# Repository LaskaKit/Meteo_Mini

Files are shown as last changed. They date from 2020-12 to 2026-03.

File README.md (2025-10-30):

# LaskaKit Meteo Mini with ESP32-C3 — More Powerful and Energy Efficient

A weather station is one of the most popular projects among makers.  
Blinking an LED is fun at first, but it gets boring quickly.  
When you build your own weather station, it will serve you for a long time — the longer it runs, the better, as you’ll collect long-term statistics.  
And with your own station, you might even detect a volcanic eruption on the other side of the world (thanks to a pressure sensor recording the shockwave).

We know not everyone can or wants to design their own hardware, so we’re introducing our development board designed specifically (but not only) for weather stations — [**LaskaKit Meteo Mini**](https://www.laskakit.cz/laskakit-meteo-mini).

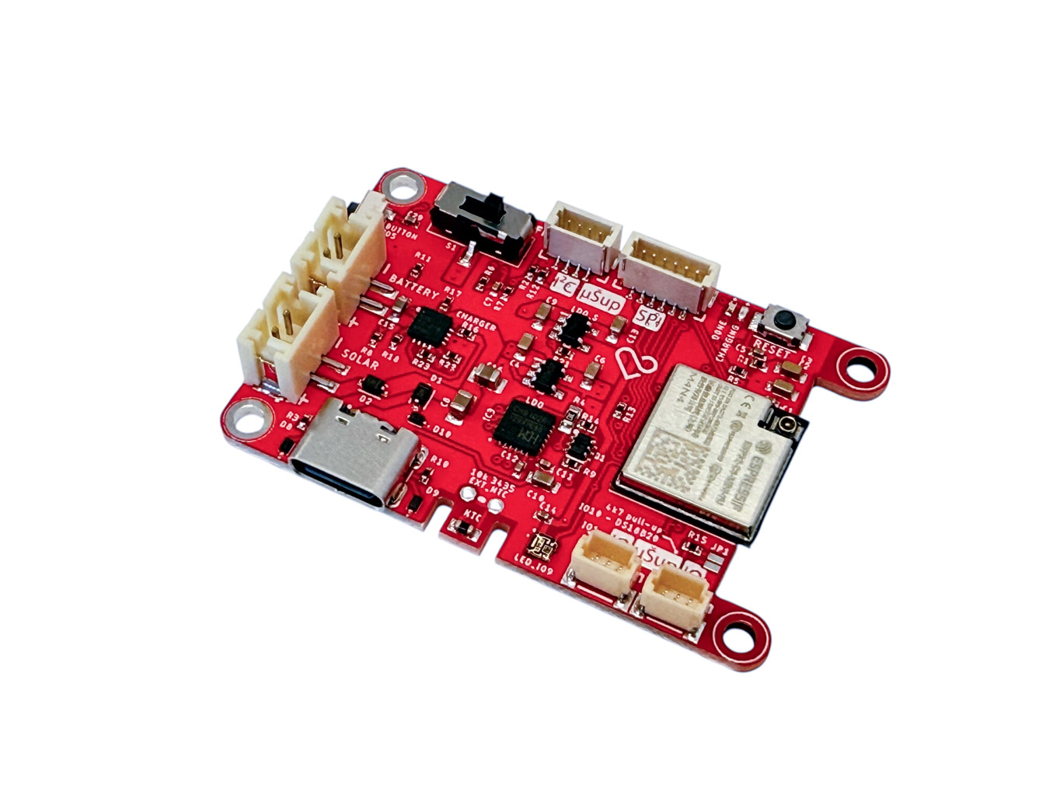
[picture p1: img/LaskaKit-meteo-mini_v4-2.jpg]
LaskaKit Meteo Mini v4.1 and newer


This development board based on **ESP32-C3** (a major upgrade from the older, less efficient ESP12S/ESP8266 version) makes building your weather station easier.  
It includes everything you need to get started — and can be easily expanded with additional sensor modules.

---

## 🧩 Specifications

| Parameter | Value |
|---|---|
| **Board version** | v4.1 |
| **Microcontroller** | ESP32-C3-MINI (Wi-Fi, BLE, RISC-V core) |
| **USB input voltage** | 3.4–5.5 V |
| **Solar input voltage** | 5–10 V *(recommended 6 V solar panel)* |
| **Deep-sleep current consumption** | 23 μA |
| **Antenna connector (IPEX version)** | [IPEX3](https://www.laskakit.cz/vyhledavani/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) |
| **Power supply** | USB-C or single-cell Li-Ion battery |
| **Charging IC** | BQ24074RGTR with charging indicators *(LED CHG/POWER GOOD)*.NTC allows battery charging only within the safe temperature range of 0 °C to 50 °C. |
| **USB interface** | CH9102F |
| **Voltage regulators** | RT9080 (ESP), RT9080 (peripherals, IO4 → HIGH to enable) |
| **Dimensions** | 48.4 × 32.9 × 9 mm |
| **Weight** | 8 g |

---

## ⚙️ Board Pinout

On the front of the board, you’ll find the Wi-Fi module with ESP32-C3.  
It delivers higher performance than the older ESP8266 version and is much more energy-efficient — consuming only **23 μA** in deep-sleep mode.

The module supports **IEEE 802.11 b/g/n** Wi-Fi standards.  
The **CH_CURRENT** solder bridge allows you to set the maximum charging current for the battery: **1.0 A or 1.34 A**, depending on resistor configuration (see schematic).

The board can be powered off using the onboard power switch.  
On the right side, there’s a **USB-C connector** for charging and power input.  
At the bottom, you’ll find connectors for a **Li-Ion battery (Battery)** and a **solar panel (Solar)**.

On the right side, there’s also a **1-Wire interface** for the **DS18B20 temperature sensor** (GPIO10).  
On the left side, you’ll find a set of **µSup connectors** – our custom connector standard compatible with **SparkFun Qwiic** and **Adafruit STEMMA**.  
In addition to the standard **I2C µSup connector**, there are also **µSup SPI** and **µSup IO** connectors.

Power for the µSup connectors is controlled via **GPIO4 (HIGH = enabled)**, allowing for even lower power consumption.  
A 3.3 V voltage regulator is integrated directly on the board.  
Battery voltage is measured using a voltage divider (1 MΩ and 1.3 MΩ) connected to **IO0 (ADC input)**.

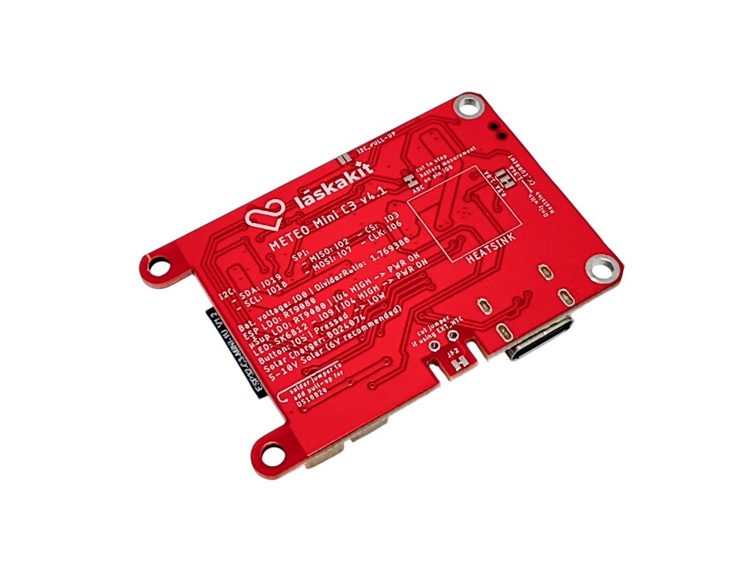
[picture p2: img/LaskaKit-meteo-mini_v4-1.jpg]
LaskaKit Meteo Mini with ESP32-C3 pinout


---

## 🔌 Sensor Connections

| Interface | Connector | Signals |
|---|---|---|
| **µSup I2C** | JST-SH 4-pin | SDA: IO19, SCL: IO18 |
| **µSup SPI** | JST-SH 6-pin | CS: IO3, MOSI: IO7, SCK: IO6, MISO: IO2 |
| **µSup IO** | 2× JST-SH 3-pin | IO1, IO10 *(supports DS18B20)* |

---

## ⚡ Battery and Solar Panel Connection

Power from USB-C and the solar panel is combined through protection diodes into the input of the **BQ24074** charging IC.  
Connecting both power sources simultaneously is safe.  
The **recommended solar panel** is 6 V, but **10 V panels can also be safely used**.  
Charging current is **configurable using the CH_CURRENT solder jumpers**: **0.5 A (default)**, **1.0 A**, or **1.34 A** *(when all three jumpers are bridged)*.  
Charging status is indicated by LEDs — **CHG** (charging) and **POWER GOOD** (fully charged).

---

## 🔋 Battery Voltage Measurement

The battery voltage (**VCC**) is connected through a resistor divider to the **IO0 (ADC)** input of the ESP32-C3 microcontroller.

---

## 💡 LEDs and Sensors

- **Addressable RGB LED:** SK6812-EC20 on IO9  
- **Button:** IO5 → pressed = LOW  
- **Temperature sensor:** NTC 10 kΩ (3435) – for battery temperature monitoring  

---

## 🧠 Programming

Install [ESP32-C3 support](https://github.com/espressif/arduino-esp32) in Arduino IDE.  
For versions **3.5 and newer** (including **v4.1**), **no external programmer** is required — the CH9102F interface is already integrated on the board.  
Older versions can use the [CH340C programmer](https://www.laskakit.cz/laskakit-ch340-programmer-usb-c--microusb--uart/).

---

## 💾 Example Code

Example code and libraries are available here:  
👉 [https://github.com/LaskaKit/Meteo_Mini/tree/main/SW/](https://github.com/LaskaKit/Meteo_Mini/tree/main/SW/)

---

## 📦 Availability

The board is available in two variants:  
- with an **integrated PCB antenna**  
- or with an **external antenna connector (IPEX3)**  

👉 [https://www.laskakit.cz/laskakit-meteo-mini/](https://www.laskakit.cz/laskakit-meteo-mini/)

---

## 🧱 3D Printed Case

A 3D-printable case model is available:

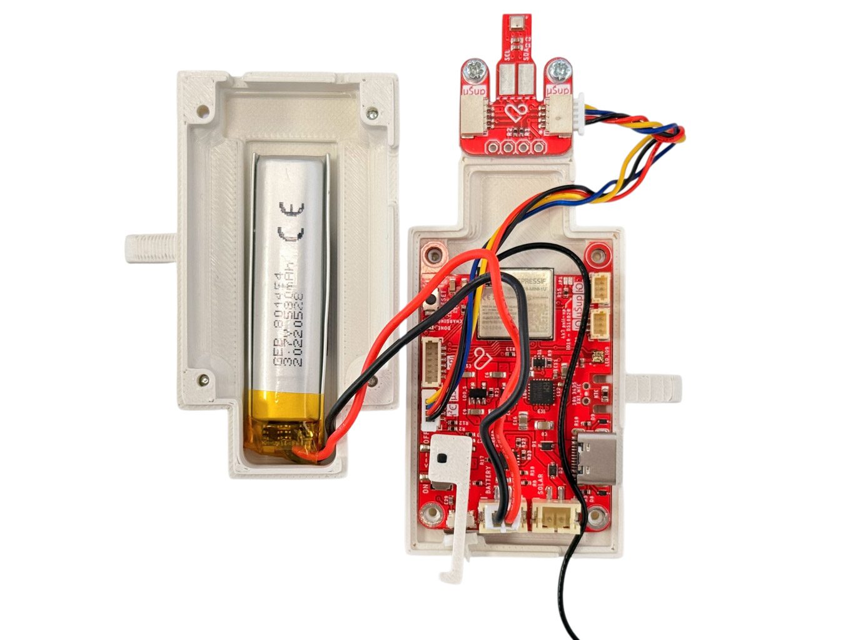
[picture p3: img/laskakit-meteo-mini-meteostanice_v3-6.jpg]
LaskaKit Meteo Mini 3D case


And yes — **we actually use what we sell** (photo of an earlier version):

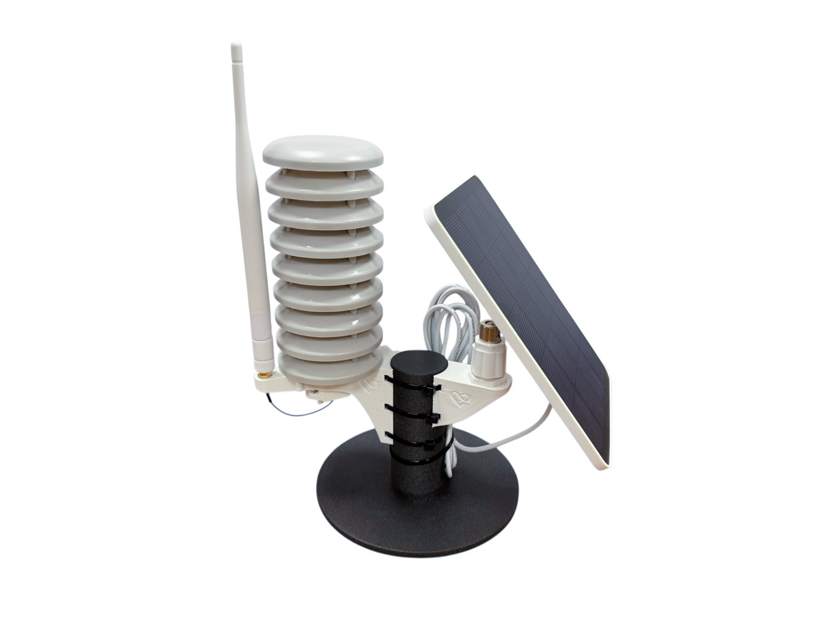
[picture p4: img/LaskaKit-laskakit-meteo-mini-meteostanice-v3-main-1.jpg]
LaskaKit Meteo Mini Weather Station


---

## 🕹️ Older Board Version

### Meteo Mini v3.5
- **IO3** was used to enable peripherals (µSup connector power).  
- **Maximum solar panel input voltage:** 6 V.  
- Charging IC: **TP4054** – lower efficiency, no direct solar input support.  
- No µSup SPI or µSup IO connector.

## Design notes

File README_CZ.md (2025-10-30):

# LaskaKit Meteo Mini s ESP32-C3 — výkonnější a úspornější

Meteostanice je jeden z projektů, které bastlíři nejčastěji vyhledávají.  
Když si blikáš LEDkou, je to sice pěkné, ale za chvíli tě to asi omrzí.  
Když si postavíš meteostanici, bude ti sloužit dlouho — vlastně čím déle, tím lépe, protože budeš mít dlouhodobé statistiky.  
A třeba díky vlastní meteostanici dokážeš zachytit výbuch sopky na druhé straně zeměkoule (díky čidlu tlaku, které zaznamená tlakovou vlnu).

Víme, že každý si nedokáže nebo nechce navrhnout vlastní hardware, a tak přicházíme s naší vývojovou deskou určenou (nejen) pro meteostanice — [**LaskaKit Meteo Mini**](https://www.laskakit.cz/laskakit-meteo-mini).

LaskaKit Meteo Mini v4.1 a novější

Tato vývojová deska s **ESP32-C3** (což je výrazná změna oproti starší méně úsporné verzi s ESP12S/ESP8266) ti ulehčí tvůj projekt meteostanice.  
Obsahuje totiž vše, co budeš pro začátek potřebovat — a velmi snadno ji rozšíříš o další moduly s čidly.

---

## 🧩 Specifikace

| Parametr | Hodnota |
|---|---|
| **Verze desky** | v4.1 |
| **Mikrokontrolér** | ESP32-C3-MINI (Wi-Fi, BLE, RISC-V jádro) |
| **Vstupní napětí USB** | 3.4–5.5 V |
| **Vstupní napětí Solar** | 5–10 V *(doporučený 6 V solární panel)* |
| **Odběr proudu v deep-sleep módu** | 23 μA |
| **Konektor pro anténu (IPEX verze)** | [IPEX3](https://www.laskakit.cz/vyhledavani/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) |
| **Napájení** | USB-C nebo Li-Ion akumulátor (1 článek) |
| **Nabíjecí čip** | BQ24074RGTR s indikací nabíjení *(LED CHG/POWER GOOD)*. NTC zajišťuje, že se baterie nabíjí pouze v bezpečném teplotním rozmezí od 0 °C do 50 °C.|
| **USB převodník** | CH9102F |
| **Stabilizátory napětí** | RT9080 (ESP), RT9080 (periferie, IO4 → HIGH pro zapnutí) |
| **Rozměry** | 48,4 × 32,9 × 9 mm |
| **Hmotnost** | 8 g |

---

## ⚙️ Pinout desky

Na přední straně desky najdeš Wi-Fi modul s ESP32-C3.  
Ten disponuje vyšším výkonem než starší verze s ESP8266 a také je mnohem úspornější — vlastní spotřeba pouhých **23 μA** v deep-sleep módu.

Tento modul podporuje standard **IEEE 802.11 b/g/n**.  
Pájecí můstek **CH_CURRENT** umožňuje volit maximální nabíjecí proud do akumulátoru: **1,0 A nebo 1,34 A** dle osazení rezistoru (viz schéma).

Desku lze vypnout pomocí vypínače na levé straně.  
Na pravé straně se nachází **USB-C konektor** pro napájení a nabíjení akumulátoru.  
Na spodní straně najdeš konektor pro **Li-Ion akumulátor (Battery)** a **solární panel (Solar)**.

Na pravé straně je také **1-Wire sběrnice** pro čidlo **DS18B20** (GPIO10).  
Na levé straně se nachází sada **µŠup konektorů** – to je náš vlastní standard kompatibilní se **SparkFun Qwiic** a **Adafruit STEMMA**.  
Kromě klasického **I2C µŠup konektoru** je zde také **µŠup SPI** a **µŠup IO**.

Napájení µŠup konektorů je řízeno přes **GPIO4 (HIGH = zapnuto)**, což umožňuje ještě nižší spotřebu.  
Regulátor napětí 3.3V je integrován přímo na desce.  
Pro měření napětí akumulátoru je k dispozici odporový dělič (1MΩ a 1,3MΩ) připojený na **IO0 (ADC vstup)**.

LaskaKit Meteo Mini s ESP32-C3 pinout  

---

## 🔌 Připojení senzorů

| Rozhraní | Konektor | Signály |
|---|---|---|
| **µŠup I2C** | JST-SH 4 pin | SDA: IO19, SCL: IO18 |
| **µŠup SPI** | JST-SH 6 pin | CS: IO3, MOSI: IO7, SCK: IO6, MISO: IO2 |
| **µŠup IO** | 2× JST-SH 3 pin | IO1, IO10 *(podpora DS18B20)* |

---

## ⚡ Připojení akumulátoru a solárního panelu

Napájení přes USB-C a solární panel je sloučeno přes ochranné diody do vstupu nabíjecího čipu **BQ24074**.  
Souběžné připojení obou zdrojů je tedy bezpečné.  
Doporučený **solární panel je 6 V**, maximálně však lze bezpečně použít i **10V solární panely**.  
Nabíjecí proud je **nastavitelný pomocí pájecích propojek CH_CURRENT** na hodnoty **0.5 A (výchozí)**, **1.0 A**, nebo **1.34 A** *(pokud jsou všechny tři propojky spojeny)*.  
Stav nabíjení je indikován pomocí LED — **CHG** (nabíjení) a **POWER GOOD** (nabito).

---

## 🔋 Měření napětí na akumulátoru

Napětí akumulátoru (**VCC**) je přes odporový dělič přivedeno na vstup **IO0** (ADC) mikrokontroléru ESP32-C3.  

---

## 💡 LED a senzory

- **Adresovatelná RGB LED:** SK6812-EC20 na pinu IO9  
- **Tlačítko:** IO5 → stisk = LOW  
- **Teplotní čidlo:** NTC 10 kΩ (3435) – ochrana akumulátoru  

---

## 🧠 Programování

V Arduino IDE nainstalujte [podporu ESP32-C3](https://github.com/espressif/arduino-esp32).  
Pro verze **3.5 a novější** (včetně **v4.1**) již **není potřeba externí programátor** — CH9102F je integrován na desce.  
U starších verzí lze použít [programátor s CH340C](https://www.laskakit.cz/laskakit-ch340-programmer-usb-c--microusb--uart/).

---

## 💾 Vzorový kód

Vzorové kódy a knihovny jsou dostupné na:  
👉 [https://github.com/LaskaKit/Meteo_Mini/tree/main/SW/](https://github.com/LaskaKit/Meteo_Mini/tree/main/SW/)

---

## 📦 K dispozici

Deska je dostupná ve dvou variantách:  
- s **integrovanou PCB anténou**  
- nebo s **konektorem pro externí anténu (IPEX3)**  

👉 [https://www.laskakit.cz/laskakit-meteo-mini/](https://www.laskakit.cz/laskakit-meteo-mini/)

## 🧱 Krabička a 3D tisk

K dispozici je i model pro 3D tisk krabičky:

LaskaKit Meteo Mini 3D case

A ano — **to, co prodáváme, sami používáme** (na fotce předchozí verze):

LaskaKit Meteo Mini Weather Station

---

## 🕹️ Starší verze desky

### Meteo Mini v3.5
- **IO3** slouží k zapnutí periferií (napájení µŠup konektorů).  
- **Maximální vstupní napětí solárního panelu:** 6 V.  
- Nabíjecí čip **TP4054** – nižší účinnost a bez podpory přímého napájení z panelu.  
- Bez SPi a IO µŠup konektoru

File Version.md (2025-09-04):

### Version 4.1
- Added 47uF capacitor for ESP
- Added pull-up on IO8
#### Version 4.0
- Made it smaller
- Redo power line, LDO chnaged to RT9080
- Wemos pins deleted
- added Neopixel LED
- added µŠup SPI connector+
- added 2x µŠup IO connectors (one with optional pull-up for DS18B20)
#### Version 3.6
- přidán kondenzátor C8 na vstup spínače AP2191
#### Version 3.5
* nevypíná se spínaný stabilizátor pokud není na výstup připojena zátěž a deska v deepsleepu bere cca 200uA.
problém odstraněn přidáním kondenzátoru C8 na vstup spínače AP2191
- změna modulu ESP na ESP32-C3-MINI
- integrován programátor
- přidán spínaný stabilizátor pro napájení periferií - AP2191WG + ME6211C33M5G (pin IO03)
#### Version 3.2
- i2C pins were swapped to mit Wemos D1 mini shields spec. | Piny i2C byly prohozený aby odpovídali shieldům pro Wemos D1.
- ADC jumper now is closed by default | Propojka ADC je nyní ve výchozím nastavení uzavřena
#### Version 3.1
Adjusted resistor values in the resistance divider to 1M/1.3M, ADC max. input voltage stays the same. | Upraveny hodnoty rezistorů v odporovém děliči na 1M/1.3M, ADC max. vstupní napětí zůstává stejné.
#### Version 3.0
Change ESP12 to ESP32-C3| Změna ESP12 na ESP32-C3
#### Version 2.2
- Voltager devider GPIIO0 (Bat_ADC) changed to 100k/130k ADC max. input voltage is 4.423 V | Dělič napětí GPIIO0 (Bat_ADC) změněn na 100k/130k ADC max. vstupní napětí je 4,423 V
- Voltager devider GPIIO1 (Solar_ADC) changed to 1M/330k ADC max. input voltage is 10.076 V | Dělič napětí GPIIO1 (Solar_ADC) změněn na 1M/330k ADC max. vstupní napětí je 10.076 V
#### Version 2.1
- Initial | Počáteční

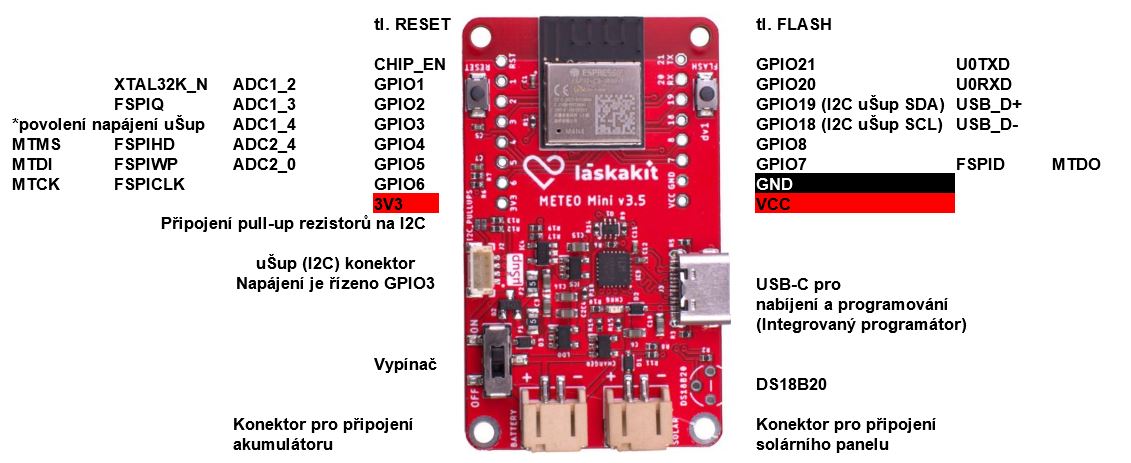
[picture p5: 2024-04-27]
img/MeteoMini-C3_v3.5_pinout.JPG

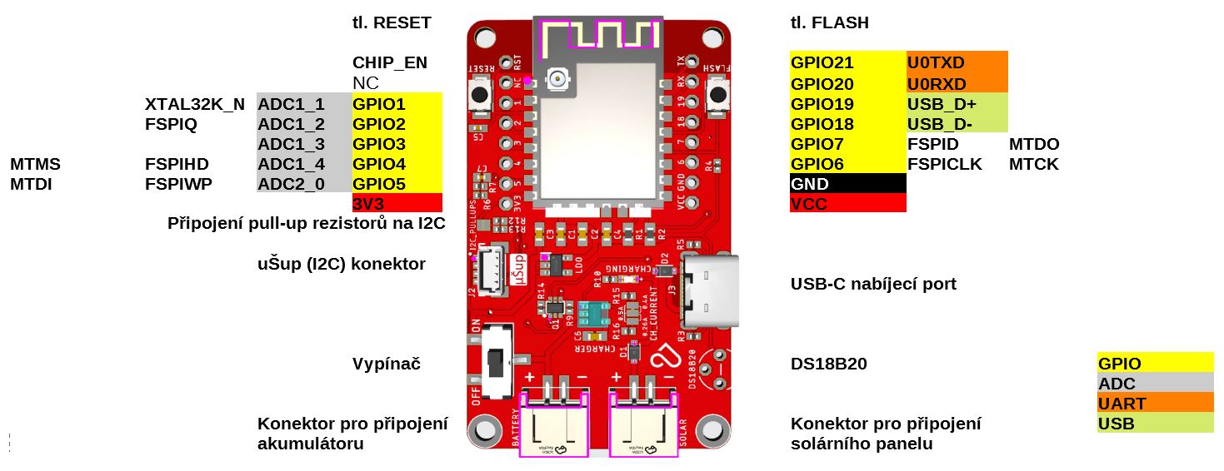
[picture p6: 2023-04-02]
img/MeteoMini_ESP32-C3_pin.jpg

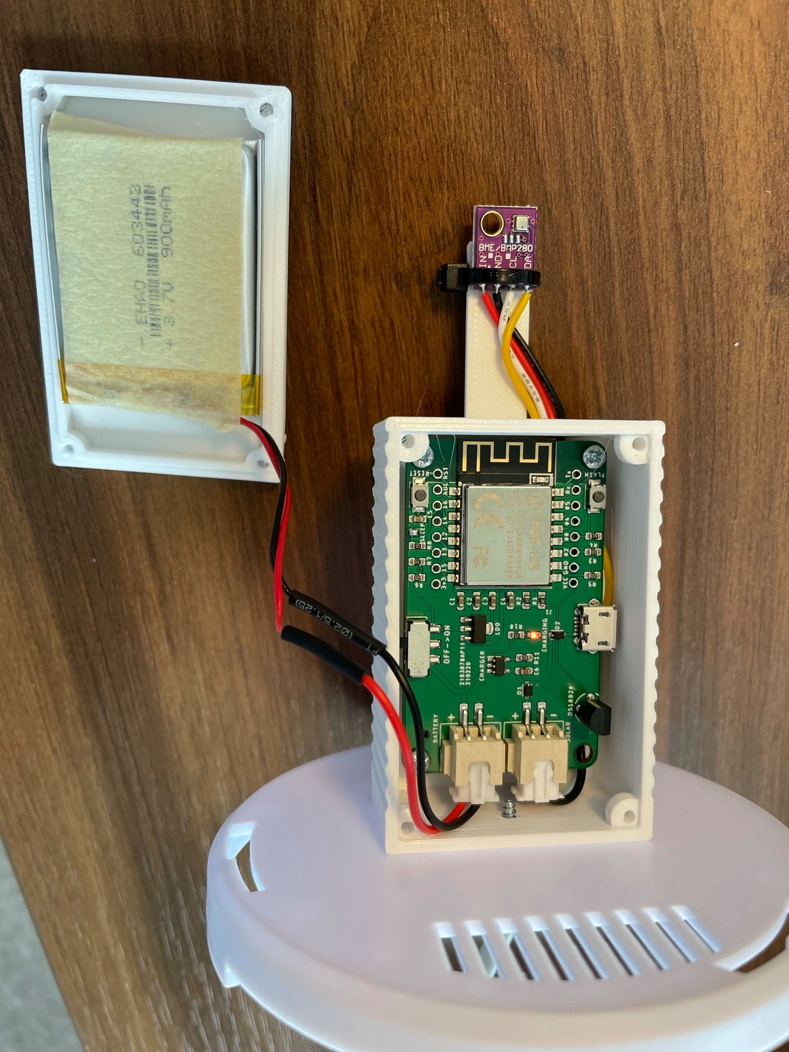
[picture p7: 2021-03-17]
img/MeteoMini_3Dcase.jpg

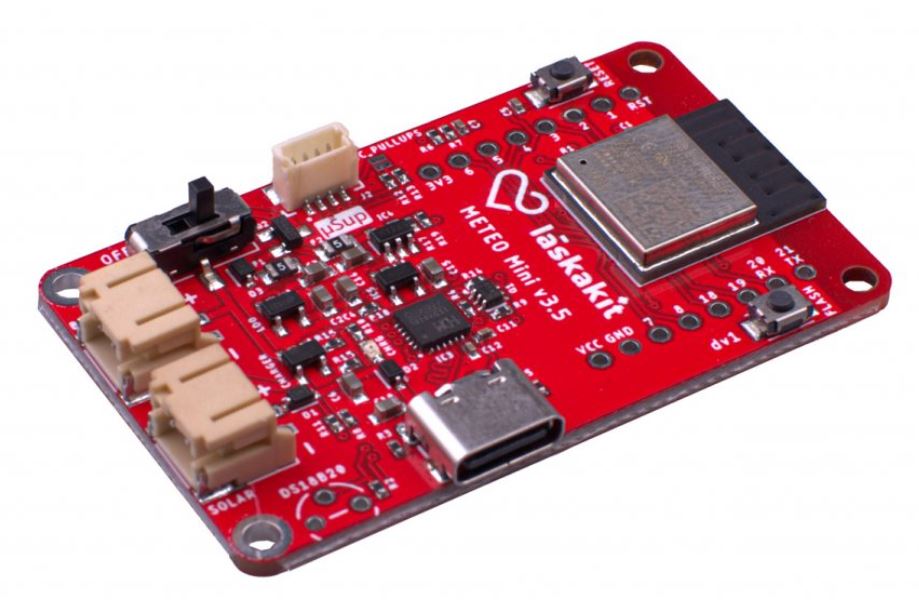
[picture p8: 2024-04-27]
img/MeteoMini-C3_v3.5_1.JPG

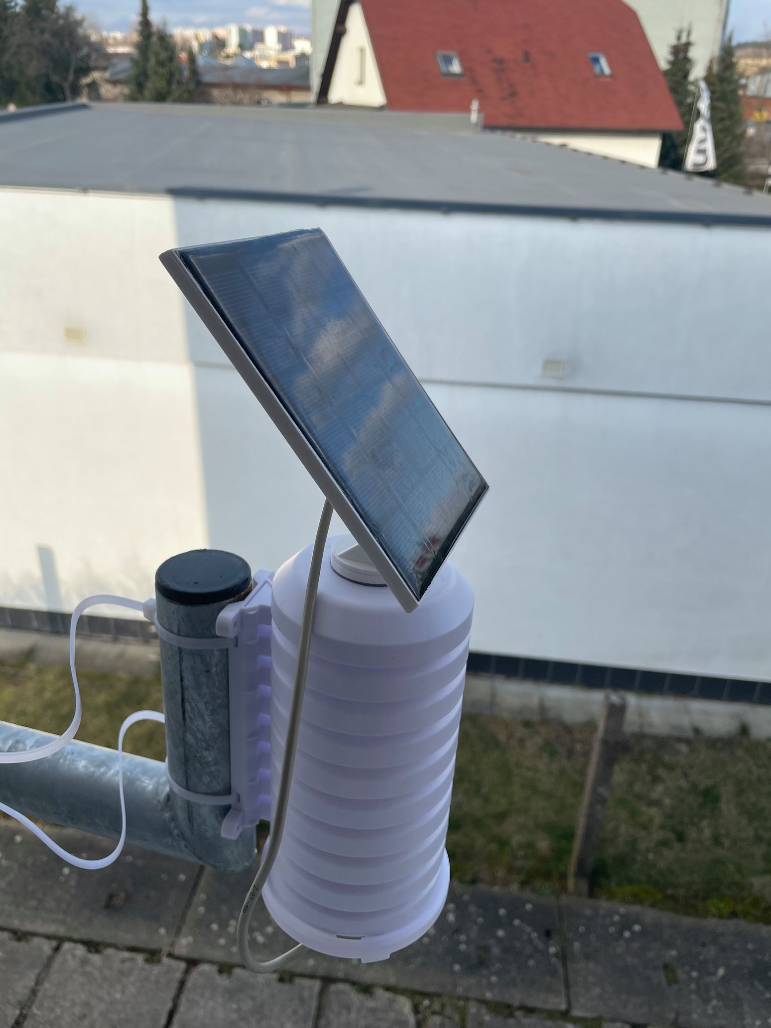
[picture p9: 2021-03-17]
img/MeteoMini_weatherstation.jpg

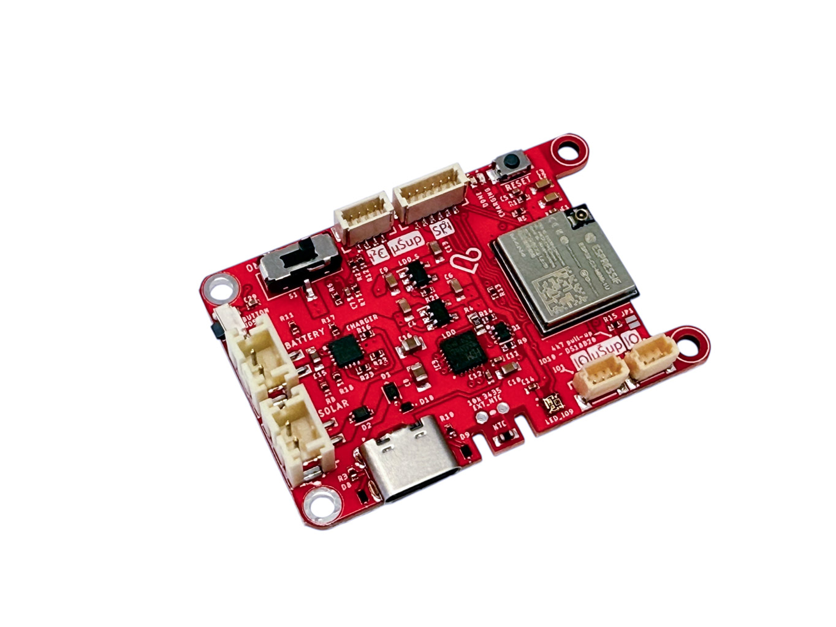
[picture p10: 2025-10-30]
img/LaskaKit-meteo-mini_v4-3.jpg

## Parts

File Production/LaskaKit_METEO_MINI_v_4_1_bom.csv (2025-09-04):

Comment | Designator | Footprint | LCSC Part #
1.3M | R7 | R0402
1M | R6 | R0402
1TS003B-1600-3500A | BUTTON | 1TS003B16003500A
1k | R11 R16 | R0402
1uF | C29 | C0402
2k | R8 | R0402
4.7k | R2 R12 R15 | R0402
5.1k | R3 R10 | R0402
10k | R1 | R0402
10k | R4 | R0603
10k | R5 R9 R13 R14 R17 R18 R21 R22 R23 | R0402
10uF/10V | C15 | C0603
10uF/16V | C4 C6 C9 C13 | C0603
22uF | C10 | C0603
47uF | C2 C3 | C0603
47uF | C8 C16 | C0805
100n | C11 C12 | C0402
100nF | C1 C5 C7 C14 | C0402
BAT60B | D1 D2 | SOD323-R
BQ24074RGTR | CHARGER | QFN50P300X300X100-17N
CH9102F | IC3 | QFN24-4X4
ESP32-C3-MINI-1-N4 | IC1 | ESP32C3MINI1N4
GREEN | DONE | CHIPLED_0402 | C130723
JST-PH-2_SMD/SMD | BATTERY SOLAR | B2B-PH-SM4 | C160352
JST-SH-4P | J2 | 1X04_1MM_RA_VERT | C7430453
LESD5D5.0CT1G | D8 D9 D10 | LESD5D50CT1G
MMDT3904 | Q1 | SC70-6 | C268586
NTC 10k 3435 | NTC | R0603 | C2889048
RED | CHARGING | CHIPLED_0402 | C21260817
RT9080-33GJ5 | LDO LDO_S | SOT94P280X100-5N
SK6812-EC20 | LED_IO9 | SK6812EC20
SLIDE_SWITCH_TA-3530A-A1 | S1 | TA-3530A-A1 | C514024
TS-1088R-02026 | RESET | TS1088R02026
USB-C_GT-USB-7010B | J6 | G-SWITCH_GT-USB-7010B | C2837092
USUP_3P_V | J3 J5 | 1X03_1MM_RA_VERT | C160389
USUP_SPI_CONNECTOR_VERT | J1 | 1X06_1MM_RA_VERT | C7430455

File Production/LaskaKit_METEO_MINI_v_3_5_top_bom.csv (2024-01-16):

Comment | Designator | Footprint | LCSC Part #
1.3M | R7 | R0402
1M | R6 R17 | R0402
1k | R10 | R0402
1k65 | R15 | R0402
3k3 | R16 | R0402
4k7 | R2 | R0402
5k1 | R3 R5 | R0402
10k | R1 R4 R9 R11 R12 R13 R14 R18 R19 | R0402
22uF | C2 C3 C4 C6 C10 C14 C15 | C0603
100k | R8 | R0402
100n | C1 C5 C7 C11 C12 | C0402
AO3401 | Q2 | SOT23
AP2191WG-7 | IC4 | SOT25 | C141321
BAT60B | D1 D2 D3 | SOD323-R
CH9102F | IC3 | QFN24-4X4
ESP32-C3-MINI-1-N4 | IC1 | ESP32C3MINI1N4
HT78XX-SOT23-5SOT23-5 | LDO | SOT23-5
JST-PH-2/90SMD | BATTERY SOLAR | S2B-PH-SM4 | C47647
JST-SH-4P/SMD | J2 | 1X04_1MM_RA_VERT | C371588
ME6211C33M5G | IC5 | SOT23-5
MMDT3904 | Q1 | SC70-6 | C268586
POLIFUSE0500805L | F1 F2 | 0805L | C66452
RED | CHRG | CHIP-LED0603
TA-3531-A2 | SW1 | TA-3530A-A2 | C514025
TP4054 | CHARGER | SOT-23-5
TS-1088R-02026 | FLASH RESET | TS1088R02026
USB-C_2-16PIN | J3 | USBC_USB-C-16P-5 | C2837092

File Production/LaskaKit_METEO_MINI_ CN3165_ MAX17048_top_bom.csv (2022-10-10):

Comment | Designator | Footprint | LCSC Part #
100n | C8 | C0402
1.2k | R7 | R0402
1k | R6 | R0402
1uF | C3 C6 C7 | C0603
3.2k | R10 | R0402
4k7 | R2 | R0603
5k1 | R3 R5 | R0402
10k | R1 | R0603
10k | R4 R9 R12 R13 R14 R17 | R0402
22k | R8 | R0402
22uF | C2 C4 | C0603
100nF | C1 | C0603
100nF | C5 | C0402K
BAT60B | D1 D2 | SOD323-R
CN3165 | U1 | DFN300X300X90-9N
ESP32-C3 | U2 | AI-THINKERESP-C3-12F_ALL
GREEN | DONE | CHIP-LED0603
HT78XX-SOT23-5SOT23-5 | LDO | SOT23-5
JST-PH-2/90SMD | BATTERY SOLAR | S2B-PH-SM4 | C47647
MAX17048 | U3 | TDFN-8 | C2682616
MMDT3904 | Q1 | SC70-6 | C268586
RED | CHARGING | CHIP-LED0603
TA-3531-A2 | SW1 | TA-3530A-A2 | C514025
TS-1088R-02026 | FLASH RESET | TS1088R02026
USB-C_2-16PIN | J3 | USBC_USB-C-16P-5 | C2837092
MSUP_V | J2 | MSUP_4P_V | C371588
NTC10k | TH1 | TH | C13879

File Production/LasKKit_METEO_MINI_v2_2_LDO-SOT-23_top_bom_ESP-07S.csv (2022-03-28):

Comment | Designator | Footprint | JLCPCB Part
1k65 | R11 | R0603 | C22845
1uF | C3 C6 | C0603
2k7 | R5 | R0603
4 7uF | C4 | C0603 | C19666
4k7 | R3 | R0603
10k | R1 R2 R4 | R0603
10k | R9 R14 | R0402
10uF | C2 | C0603
100k | R7 | R0603
100nF | C1 C5 | C0603
330 | R10 | R0603
330k | R6 | R0603
470 | R8 | R0603
BAT60B | D1 D2 | SOD323-R | C22638
ESP-07S | ESP-07S | ESP07-SMD | C82895
HT78XX-SOT23-5SOT23-5 | LDO | SOT23-5 | C164106
JST-PH-2/90SMD | BATTERY SOLAR | S2B-PH-SM4 | C47647
MMDT3904 | Q1 | SC70-6 | C268586
RED | CHARGING | CHIP-LED0603
TP4054 | CHARGER | SOT-23-5
TS-1088R-02026 | FLASH RESET | TS1088R02026
MicroXNJ | J1 | MicroXNJ | C404969
SLIDE_SW | SW1 | TA-3531-A2 | C514025

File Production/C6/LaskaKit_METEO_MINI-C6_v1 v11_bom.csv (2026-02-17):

Comment | Designator | Footprint | LCSC Part #
1.3M | R7 | R0402
1M | R6 | R0402
1TS003B-1600-3500A | BUTTON | 1TS003B16003500A
1k | R11 R16 | R0402
1uF | C29 | C0402
2k | R8 | R0402
4.7k | R2 R12 R15 | R0402
5.1k | R3 R10 | R0402
10k | R1 R5 R9 R13 R14 R17 R18 R21 R22 R23 | R0402
10uF/10V | C15 | C0603
10uF/16V | C4 C6 C9 C13 | C0603
22uF | C10 | C0603
47uF | C2 C3 | C0603
47uF | C8 C16 | C0805
100n | C11 C12 | C0402
100nF | C1 C5 C7 C14 | C0402
BAT60B | D1 D2 | SOD323-R
BQ24074RGTR | CHARGER | QFN50P300X300X100-17N
CH9102F | IC3 | QFN24-4X4
DNP - 10k | R4 | R0603
ESP32-C6-MINI-1-N4 | IC2 | ESP32C6MINI1N4
GREEN | PGOOD | CHIPLED_0402 | C20608784
JST-PH-2_SMD/SMD | BATTERY SOLAR | B2B-PH-SM4 | C160352
JST-SH-4P | J2 | 1X04_1MM_RA_VERT | C371588
JUMPER-SMT_2_NO_NO-SILK | JP1 | SMT-JUMPER_2_NO_NO-SILK
LESD5D5.0CT1G | D8 D9 D10 | LESD5D50CT1G
MMDT3904 | Q1 | SC70-6 | C268586
NTC 10k 3435 | NTC | R0603 | C2889048
RED | CHARGING | CHIPLED_0402 | C21260817
RT9080-33GJ5 | LDO LDO_S | SOT94P280X100-5N
SK6812-EC20 | LED_IO9 | SK6812EC20
SLIDE_SWITCH_TA-3530A-A2 | S1 | TA-3530A-A2 | C514025
TS-1088R-02026 | RESET | TS1088R02026
USB-C_GT-USB-7010B | J6 | G-SWITCH_GT-USB-7010B | C2837092
USUP_3P_V | J3 J5 | 1X03_1MM_RA_VERT | C160389
USUP_SPI_CONNECTOR_VERT | J1 | 1X06_1MM_RA_VERT | C145963
JUMPER-SMT_2_NC_TRACE_NO-SILK | ADC JP2 | SMT-JUMPER_2_NC_TRACE_NO-SILK
JUMPER-SMT_2_NO_NO-SILK | I2C_PULL-UP | SMT-JUMPER_2_NO_NO-SILK
JUMPER-SMT_3_1-NC_TRACE_NO-SILK | CH_CURRENT | SMT-JUMPER_3_1-NC_TRACE_NO-SILK

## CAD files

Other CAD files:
3D/LaskaKit_METEO_MINI_v_3_6.f3d

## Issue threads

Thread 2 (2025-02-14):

Problém s nahráním kódu Platformio vs Arduino Ide

tomasja6, 2025-02-14:
Dobrý den,

objevil jsem problém s deskou meteo mini v3.5. V případě, že nahrávám kód přes platformio - tak knihovna wifi.h zúůsobuje po spuštění WiFi.begin() restart ESP32-C3. Pokud je ale ten samý kód nahrán přes Arduino IDE 2.2.1 - deska funguje výborně bez restartů.

zatím jsem problem navodil vždy při nahrání přes platformio.

Platformio.ini

; PlatformIO Project Configuration File
;
;   Build options: build flags, source filter
;   Upload options: custom upload port, speed and extra flags
;   Library options: dependencies, extra library storages
;   Advanced options: extra scripting
;
; Please visit documentation for the other options and examples
; https://docs.platformio.org/page/projectconf.html

[env:esp32-c3-devkitm-1]
platform = espressif32
board = esp32-c3-devkitm-1
framework = arduino
platform_packages = toolchain-riscv32-esp @ 8.4.0+2021r2-patch5
;board_build.partitions=partitions.csv
;framework = arduino ;esp-idf ;

lib_deps =
	sparkfun/SparkFun SCD4x Arduino Library@^1.1.2
	adafruit/Adafruit BME280 Library@^2.2.4
	adafruit/Adafruit Unified Sensor@^1.1.15

testovací kód pro wifi

#include <Arduino.h>

//WiFi
#include <ESPmDNS.h>
#include <WiFi.h>

//BME280
#include <Adafruit_Sensor.h>
#include <Adafruit_BME280.h>

//SDC4x
#include <SparkFun_SCD4x_Arduino_Library.h>

//I2C
#include <Wire.h>

//webserver
//#include <WebServer.h>
  //definition webserver on port 80
  //WebServer server(80);

//WiFi connection settings
const char* ssid = "xxxxxxxxx";
const char* pass = "xxxxxxxxx";
const char* host = "meteo";

void setup() {
// serial communication inicialization
Serial.begin(115200);
Serial.println("serial initialization");
Serial.print("Connecting to WiFi ");
Serial.println(ssid);
//ESP.restart();

//WiFi connection
delay(10);

//WiFi.setTxPower(WIFI_POWER_5dBm);
WiFi.begin(ssid, pass);
delay(5000);
while (WiFi.status() != WL_CONNECTED) {
delay(500);
Serial.print(".");
}

Serial.println("Wifi connected");
Serial.print("IP : ");
Serial.println(WiFi.localIP().toString());

}

void loop(){

}

Díky za radu

tomasja6, 2025-02-19:
hmm, tak jsem musel vypnout detekci

#include "soc/soc.h"
#include "soc/rtc_cntl_reg.h"

void setup() {
    WRITE_PERI_REG(SENS_SAR_START_FORCE_REG, 0); // Vypnutí brownout detekce
    Serial.begin(115200);
}

Konstantin-G, 2025-02-20:
Zdravím, díky za zpětnou vazbu.

Closed 2025-02-20.

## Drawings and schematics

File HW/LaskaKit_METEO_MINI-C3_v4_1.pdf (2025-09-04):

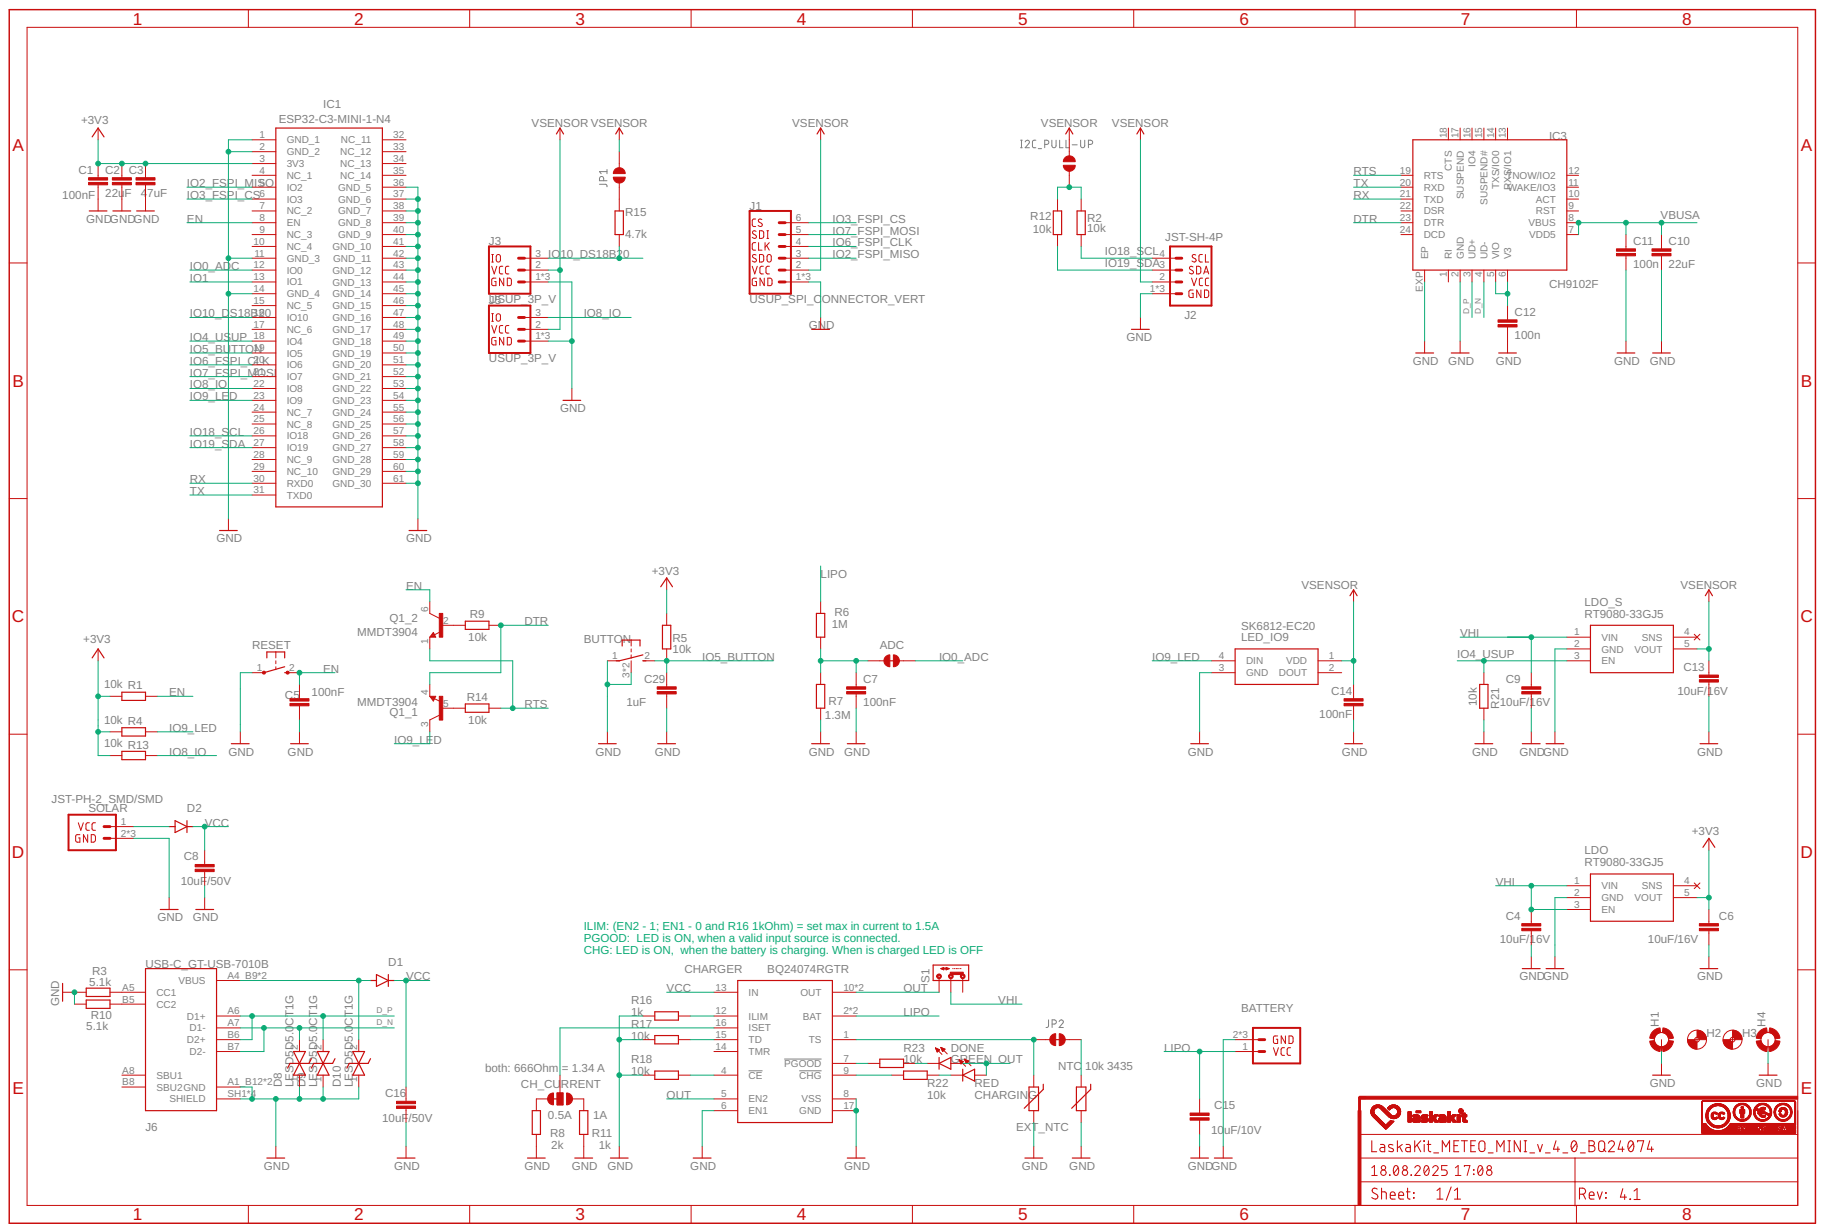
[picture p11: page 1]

ILIM: (EN2 - 1; EN1 - 0 and R16 1kOhm) = set max in current to 1.5A
PGOOD: LED is ON, when a valid input source is connected. CHG: LED is ON, when the battery is charging. When is charged LED is OFF

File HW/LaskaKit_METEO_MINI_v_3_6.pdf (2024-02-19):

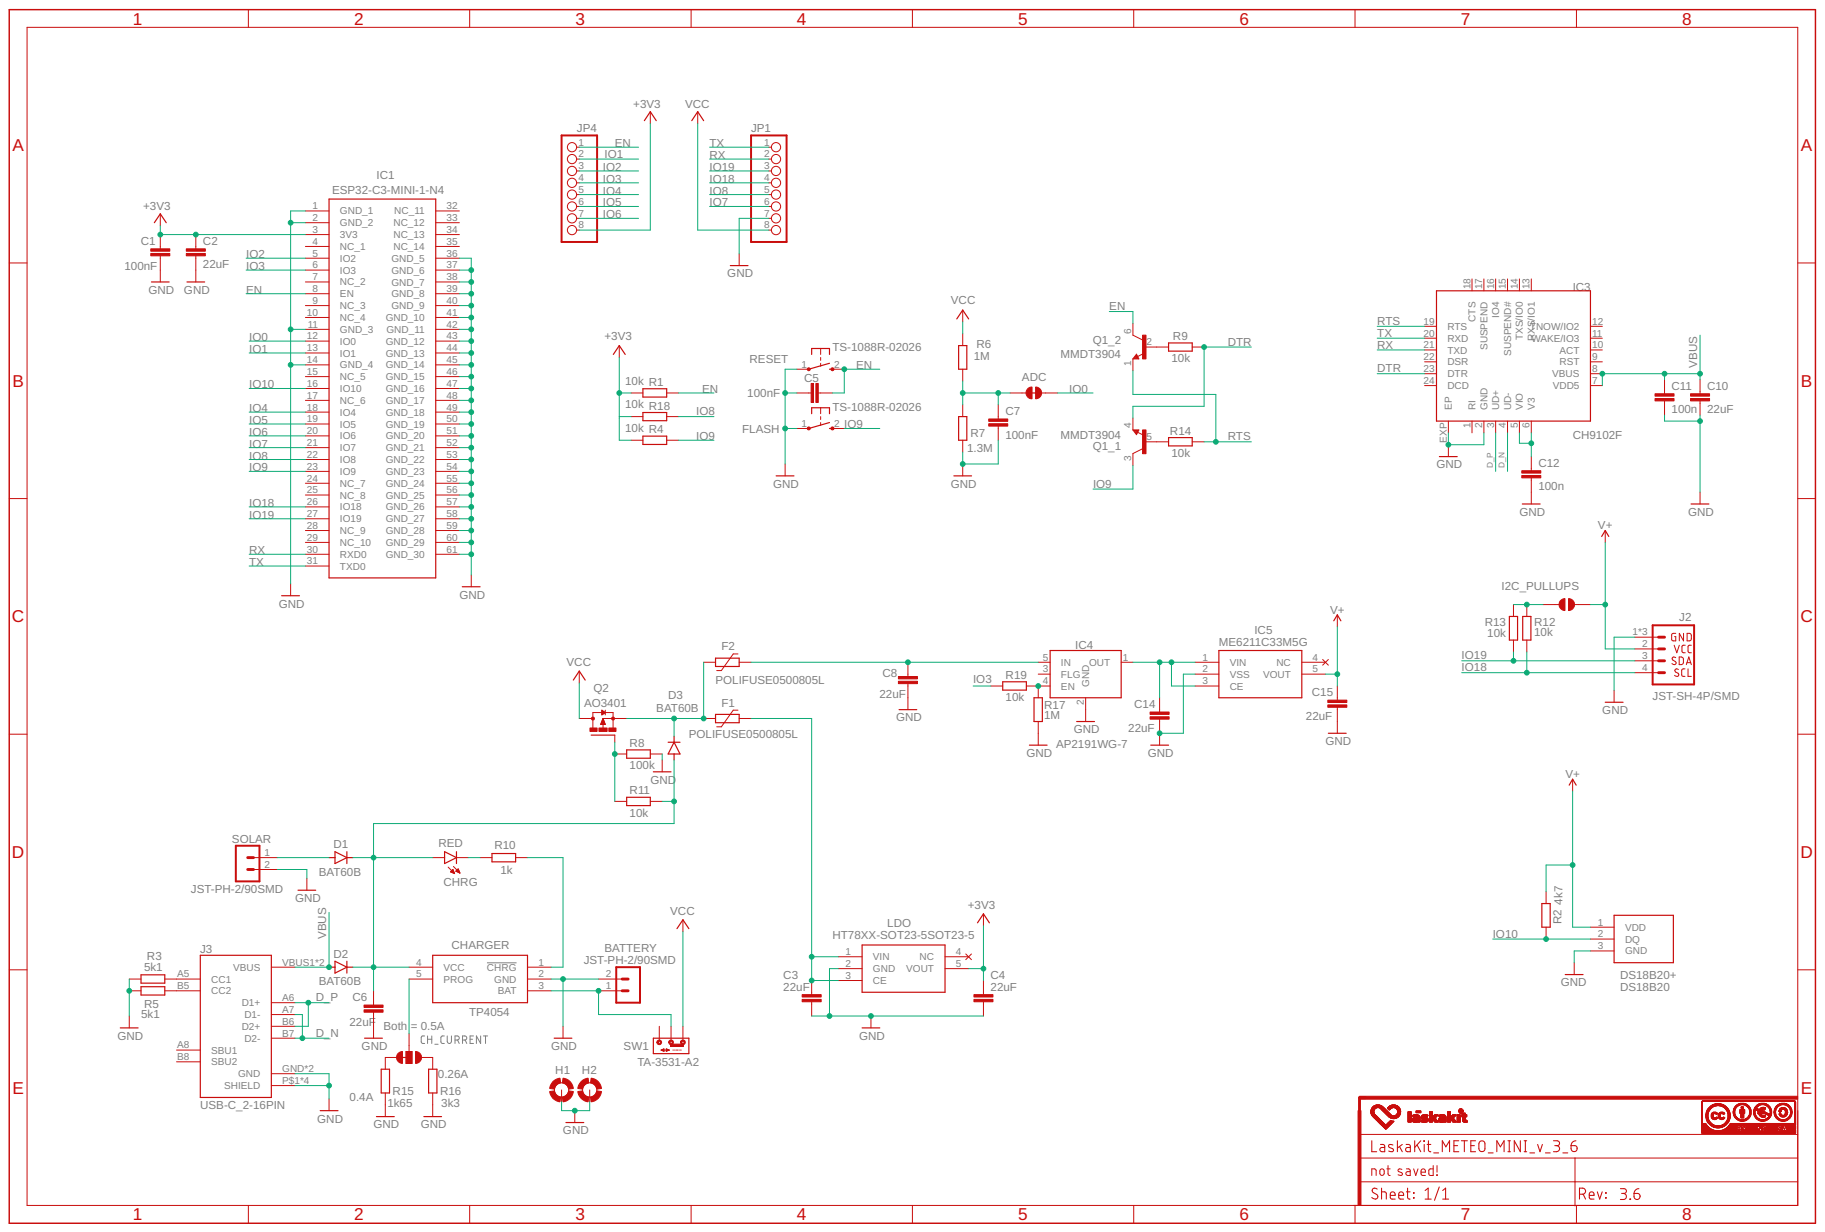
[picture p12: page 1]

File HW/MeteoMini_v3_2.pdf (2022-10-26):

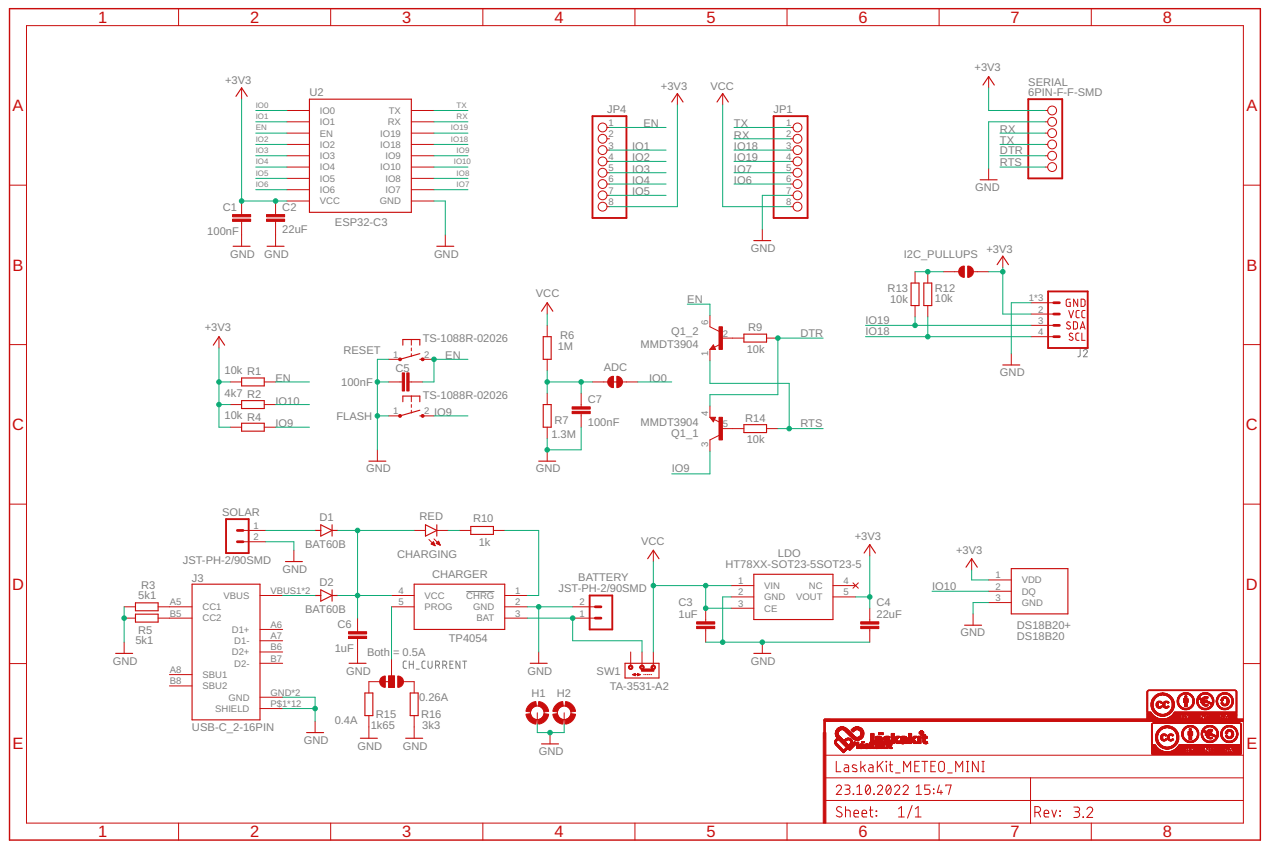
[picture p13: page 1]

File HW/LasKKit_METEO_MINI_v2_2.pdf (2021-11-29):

A

A

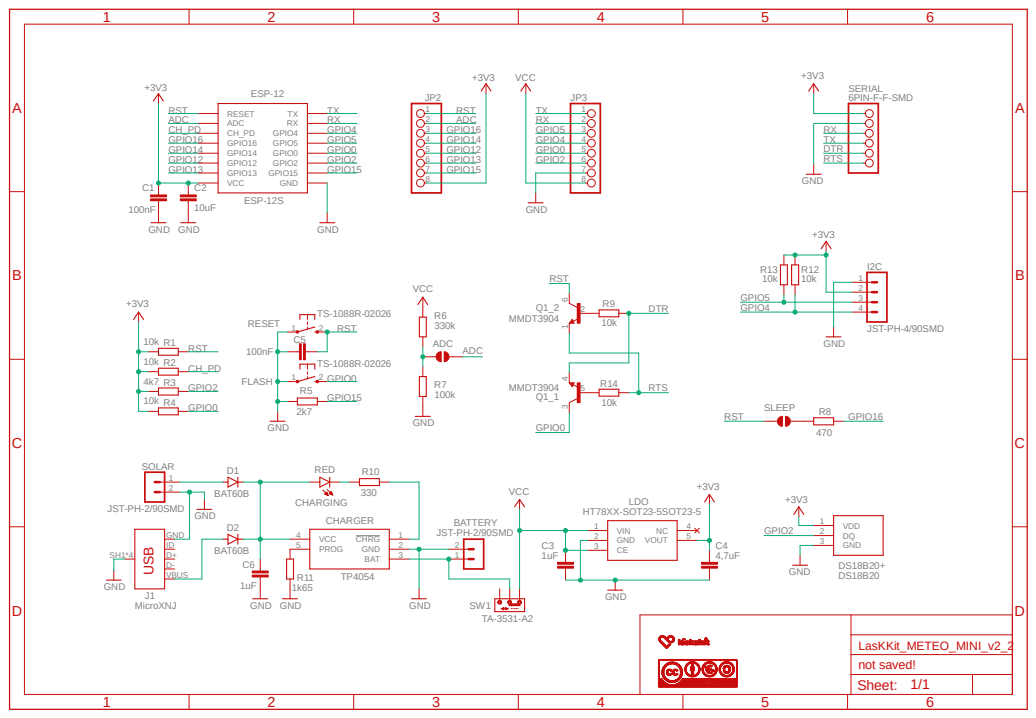
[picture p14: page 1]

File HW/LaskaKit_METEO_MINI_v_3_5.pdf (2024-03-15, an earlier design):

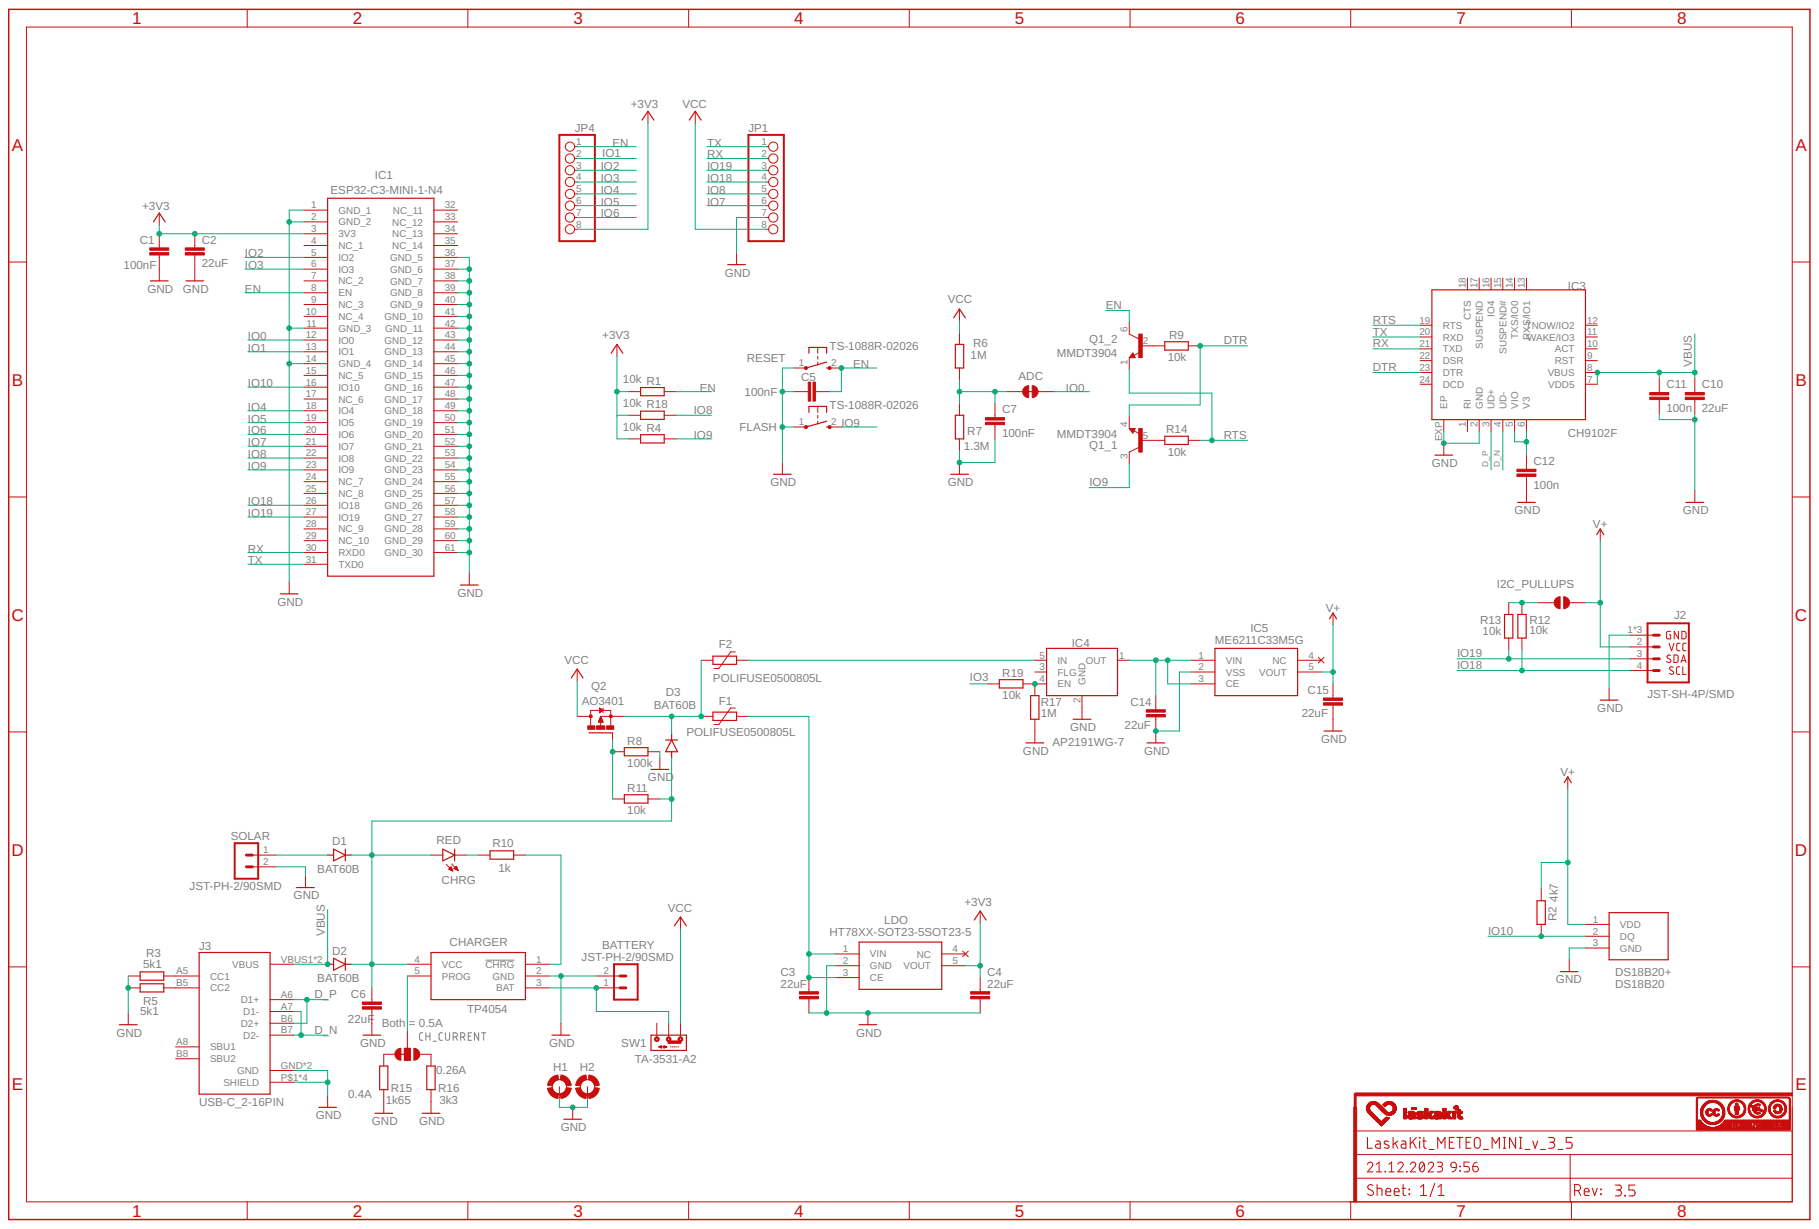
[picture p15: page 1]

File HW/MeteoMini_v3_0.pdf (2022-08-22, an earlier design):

## 8 JP1

8JP4

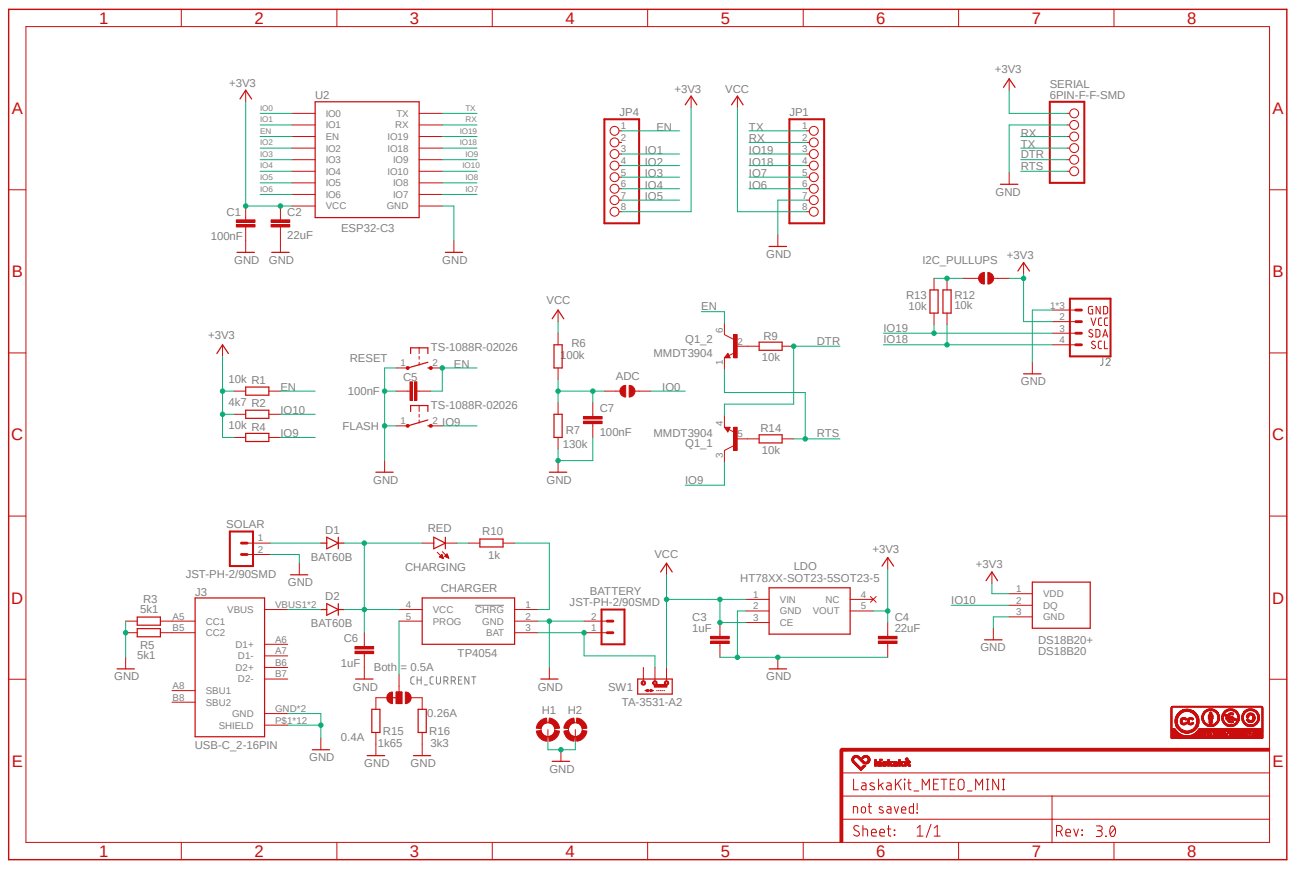
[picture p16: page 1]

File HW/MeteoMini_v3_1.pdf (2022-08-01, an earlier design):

## 8 JP1

8JP4

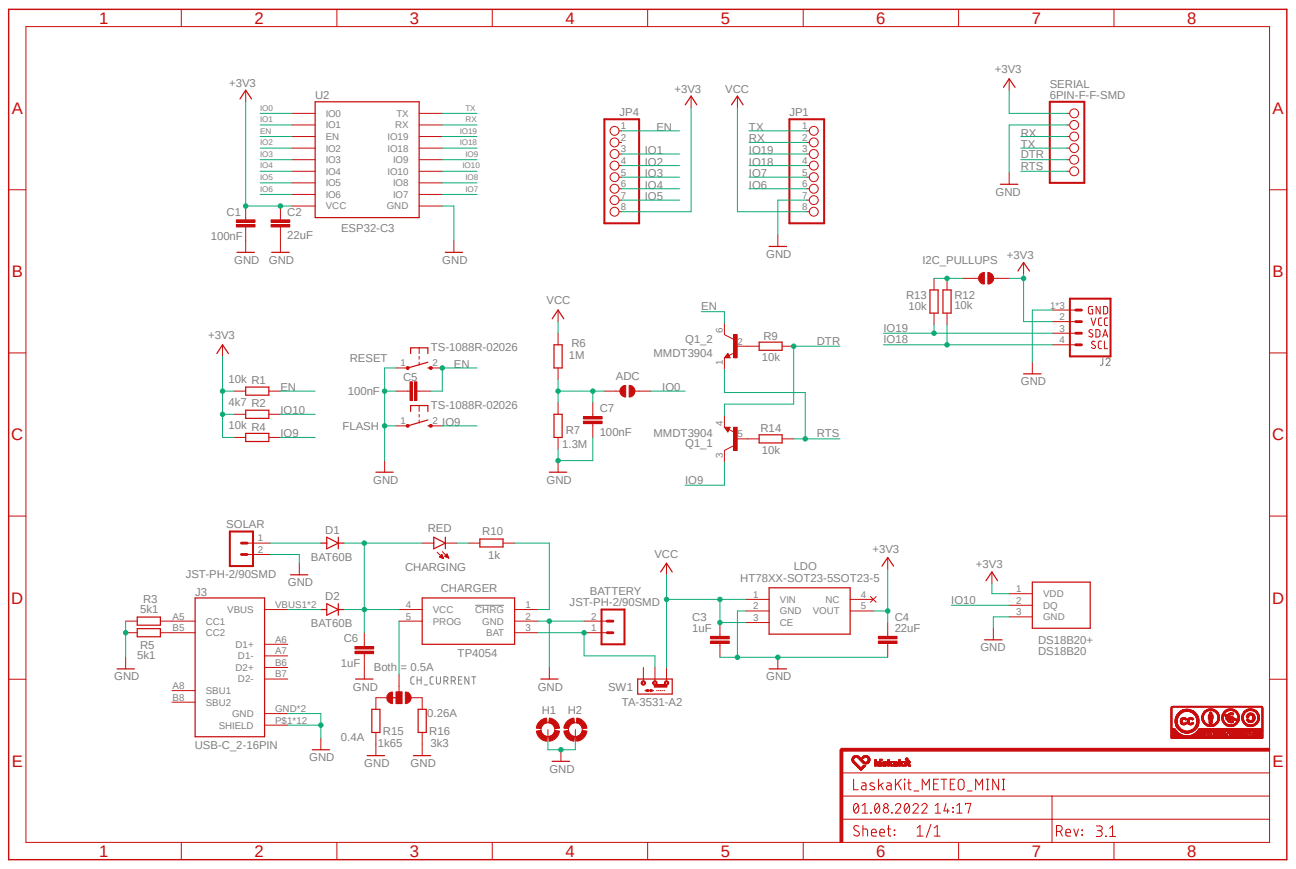
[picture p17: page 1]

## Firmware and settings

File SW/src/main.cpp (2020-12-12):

/* LasKKit DIY Mini Weather Station. 
 * Thingspeak edition
 * Read Temperature, Humidity and pressure and send to Thingspeak
 * For settings see settings.h
 * 
 * Email:obchod@laskarduino.cz
 * Web:laskarduino.cz

 * Adafruit BME280 library
 * https://github.com/adafruit/Adafruit_BME280_Library
 * Miles Burton DS18B20 library
 * https://github.com/milesburton/Arduino-Temperature-Control-Library
 */

// připojení knihoven
#include <Arduino.h>
#include "config_my.h"        // change to config.h and fill the file.

#include <Wire.h>
#include <OneWire.h>
#include <ESP8266WiFi.h>
#include <Adafruit_Sensor.h>
#include <Adafruit_BME280.h>
#include <DallasTemperature.h>

//TODO add SHT10x 
#ifdef DALLAS
#define DSPIN D4
#endif

#define BME280_ADDRESS (0x76)   // (0x77) cut left and solder right pad on board
#define OFFSET 0.00             // offset pro mereni napeti baterie
#define SLEEP_SEC 15*60         // Measurement interval (seconds)

//IPAddress ip(192,168,1,50);       // pick your own IP outside the DHCP range of your router
//IPAddress gateway(192,168,1,1);   // watch out, these are comma's not dots
//IPAddress subnet(255,255,255,0);

const char* server = "api.thingspeak.com";

// Vytvoření instance | Instance creation
OneWire oneWireDS(DSPIN);
DallasTemperature dallas(&oneWireDS);
Adafruit_BME280 bme;
WiFiClient client;

float temperature;
float pressure;
float humidity;
float volt;
float temp_in;

void postData(){
  // Odesíláni dat do ThingSpeak | Post data to ThingSpeak
  if (client.connect(server,80)) {
    Serial.println("Connect to ThingSpeak - OK"); 
    
    String dataToThingSpeak = "";
    dataToThingSpeak+="GET /update?api_key=";
    dataToThingSpeak+=api_key;
    
    dataToThingSpeak+= "&field1=";
    dataToThingSpeak+= String(temperature);
    
    dataToThingSpeak+= "&field2=";
    dataToThingSpeak+= String(pressure);
    
    dataToThingSpeak+= "&field3=";
    dataToThingSpeak+= String(humidity);
    
    dataToThingSpeak+= "&field4=";
    dataToThingSpeak+= String(volt);
    
    dataToThingSpeak+="&field5=";
    dataToThingSpeak+=String(temp_in);
    
    dataToThingSpeak+=" HTTP/1.1\r\nHost: a.c.d\r\nConnection: close\r\n\r\n";
    dataToThingSpeak+="";
    Serial.println("posting data to ThingSpeak");
    Serial.println(dataToThingSpeak);
    client.print(dataToThingSpeak);
    
    int timeout = millis() + 5000;
    while (client.available() == 0) {
      if (timeout - millis() < 0) {
        Serial.println("Error: Client Timeout!");
        client.stop();
        return;
      }
    }
  } else Serial.println("Connect to ThingSpeak - FALSE"); 
  while(client.available()){
    String line = client.readStringUntil('\r');
    Serial.print(line);
  }
}

// pripojeni k WiFi | WiFi Connection
void WiFiConnection(){
  Serial.println();
  Serial.print("Connecting to...");
  Serial.println(ssid);

 // WiFi.config(ip,gateway,subnet);   // Použít statickou IP adresu, config.h | Use static ip address, see config.h
  WiFi.begin(ssid, pass);

  while (WiFi.status() != WL_CONNECTED) {
    delay(500);
    Serial.print(".");
  }
  Serial.println("");
  Serial.println("Wi-Fi connected successfully");
}

// Přečíst data z BME280 | Read data from BME280
void readBME(){
  temperature = bme.readTemperature();
  humidity = bme.readHumidity();
  pressure = bme.readPressure() / 100.0F;  
  
  Serial.print("Temp: "); Serial.print(temperature); Serial.println("°C");
  Serial.print("Humidity: "); Serial.print(humidity); Serial.println("% RH");
  Serial.print("Pressure: "); Serial.print(pressure); Serial.println("hPa");
}

// Přečíst data z DS18B20 | Read data from DS18B20
void readDallas(){
  dallas.requestTemperatures();
  temp_in = dallas.getTempCByIndex(0);  // (0) - pořadí dle unikátní adresy čidel | Fetch temperature for device index
  
  Serial.print("Temp_in: "); Serial.print(temp_in); Serial.println(" °C");
}

// Měření napětí baterie | Battery voltage measurement
void readBat(){
  int voltraw = system_adc_read();
  volt = voltraw / 1024.0 * 4.20;
  volt = OFFSET + volt;
 
  Serial.print("Napětí baterii: "); Serial.print(volt); Serial.println(" V");
}

void setup() {
  // Hned vypneme WiFi | disable WiFi, coming from DeepSleep, as we do not need it right away
  WiFi.mode( WIFI_OFF );
  WiFi.forceSleepBegin();
  delay( 1 );

  Serial.begin(115200);
  while(!Serial) {} // Wait
  
  pinMode(A0, INPUT);

  // initilizace BME280 | BME280 Initialization
  Wire.begin();
  if (! bme.begin(BME280_ADDRESS)) {
    Serial.println("Could not find a valid BME280 sensor, check wiring!");
    while (1);
  }
  Serial.println("-- Weather Station Scenario --");
  Serial.println("forced mode, 1x temperature / 1x humidity / 1x pressure oversampling,");
  Serial.println("filter off");
  bme.setSampling(Adafruit_BME280::MODE_FORCED,
                  Adafruit_BME280::SAMPLING_X1, // temperature
                  Adafruit_BME280::SAMPLING_X1, // pressure
                  Adafruit_BME280::SAMPLING_X1, // humidity
                  Adafruit_BME280::FILTER_OFF   );

  // initilizace DS18B20 | DS18B20 Initialization
  dallas.begin();
  delay(10);

  readBME();
  readDallas();

  // Probudit WiFi | Wake up WiFi Modem
  WiFi.forceSleepWake();
  delay( 1 );
  WiFi.mode( WIFI_STA );
  
  // Pripojeni k WiFi | Connect to WiFi
  WiFiConnection();
  
  readBat();      // WiFi should be ON for ADC functionality, overwise getting 1024 reading.
  postData();

  WiFi.disconnect(true);
  delay(1);
  // ESP Deep Sleep 
  // Radio po probuzeni bude vypnuto | Radio disabled after wake up
  Serial.println("ESP8266 in sleep mode");
  ESP.deepSleep(SLEEP_SEC * 1000000, WAKE_RF_DISABLED); 
}

void loop(){
  // Nepotřebujeme loop | We dont use the loop
}

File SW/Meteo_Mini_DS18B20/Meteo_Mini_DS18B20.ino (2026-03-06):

/*
* Example code for DS18B20 and MeteoMini board with ESP32-C3/C6
* Values are sent to Serial Monitor
*
* Board:   LaskaKit Meteo Mini C3                                 https://www.laskakit.cz/laskakit-meteo-mini/
*          LaskaKit Meteo Mini C6                               
* Sensor:  Maxim Integrated DS18B20+ digital temperature sensor   https://www.laskakit.cz/dallas-ds18b20--orig--digitalni-cidlo-teploty-to-92/
*
* Library:  https://github.com/milesburton/Arduino-Temperature-Control-Library
*           https://github.com/PaulStoffregen/OneWire
* 
* Made by laskakit.cz (c) 2026
*/


#include <Wire.h>
#include <OneWire.h>
#include <DallasTemperature.h>

//#define Meteo_Mini_C3
#define Meteo_Mini_C6

#if defined(Meteo_Mini_C3)

  #define Power   4
  #define ONE_WIRE_BUS 10

#elif defined(Meteo_Mini_C6)

  #define Power   1
  #define ONE_WIRE_BUS 21

#endif

// Setup a oneWire instance to communicate with any OneWire devices (not just Maxim/Dallas temperature ICs)
OneWire oneWire(ONE_WIRE_BUS);

// Pass our oneWire reference to Dallas Temperature.
DallasTemperature sensors(&oneWire);

 
void setup() {
  Serial.begin(115200);
  while (!Serial) 
  {
    ; // cekani na Serial port
  }

  // for version over 3.5 need to turn uSUP ON
  pinMode(Power, OUTPUT);      // Set EN pin for uSUP stabilisator as output
  digitalWrite(Power, HIGH);   // Turn on the uSUP power

  sensors.begin();
}
 
/*
 * Main function, get and show the temperature
 */
void loop(void)
{
  // call sensors.requestTemperatures() to issue a global temperature
  // request to all devices on the bus
  Serial.print("Requesting temperatures...");
  sensors.requestTemperatures(); // Send the command to get temperatures
  Serial.println("DONE");
  delay(1500);
  // After we got the temperatures, we can print them here.
  // We use the function ByIndex, and as an example get the temperature from the first sensor only.
  float tempC = sensors.getTempCByIndex(0);

  // Check if reading was successful
  if (tempC != DEVICE_DISCONNECTED_C)
  {
    Serial.print("Temperature for the device 1 (index 0) is: ");
    Serial.println(tempC);
  }
  else
  {
    Serial.println("Error: Could not read temperature data");
  }
}

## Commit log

2021-02-12 hw updated
    [LasKKit_METEO_MINI_v2_1_top_cpl.csv, LasKKit_METEO_MINI_v2_top_cpl.csv]
2021-02-17 new microUSB
    [LasKKit_METEO_MINI_v2_1_top_cpl.csv]
2021-03-11 new gerber
2021-03-11 add bom
    [LasKKit_METEO_MINI_v2_1_top_bom.csv]
2021-03-19 current in deep-sleep mode
2021-11-29 new connectors
2022-03-28 added esp07
    [LasKKit_METEO_MINI_v2_2_LDO-SOT-23_top_bom_ESP-07S.csv]
2022-04-27 ESP-C3 testing
    [LasKKit_METEO_MINI_v2_2_LDO-SOT-23_top_bom.csv, LasKKit_METEO_MINI_v2_2_LDO-SOT-23_top_bom_ESP-07S.csv, LasKKit_METEO_MINI_v3_0_LDO-SOT-23_top_bom.csv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]
2022-07-19 C3 ver
    [LasKKit_METEO_MINI_v3_0_top_bom.csv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]
2022-08-01 new version, see version.md
    [LasKKit_METEO_MINI_v3_0_top_bom.csv]
2022-08-22 ADC update
2022-10-10 test version
    [LaskaKit_METEO_MINI_ CN3165_ MAX17048_top_bom.csv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]
2022-10-26 new data
    [LasKKit_METEO_MINI_v3_2_top_bom.csv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]
2023-10-03 new test data
    [LaskaKit_METEO_MINI_v_3_5_top_bom.csv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]
2023-11-01 error fixed
    [LaskaKit_METEO_MINI_v_3_5_top_bom.csv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]
2024-01-16 fixed data
    [LaskaKit_METEO_MINI_v_3_5_top_bom.csv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]
2024-08-14 new ver
    [LaskaKit_METEO_MINI_v_3_6.f3d]
2024-08-18 "Fix ADC reading"
2025-01-19 Update Meteo_Mini_ESP32-C3_TMEP_WifiManager.ino
    Suuport of two I2C address for SHT40 (0x44 and 0x45) and BME280 (0x76 and 0x77)
2025-06-19 new ver 4.0 see version.md
    [LaskaKit_METEO_MINI_v_4_0_bom.csv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]
